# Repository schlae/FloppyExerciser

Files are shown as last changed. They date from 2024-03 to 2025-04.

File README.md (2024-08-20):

# Floppy Exerciser

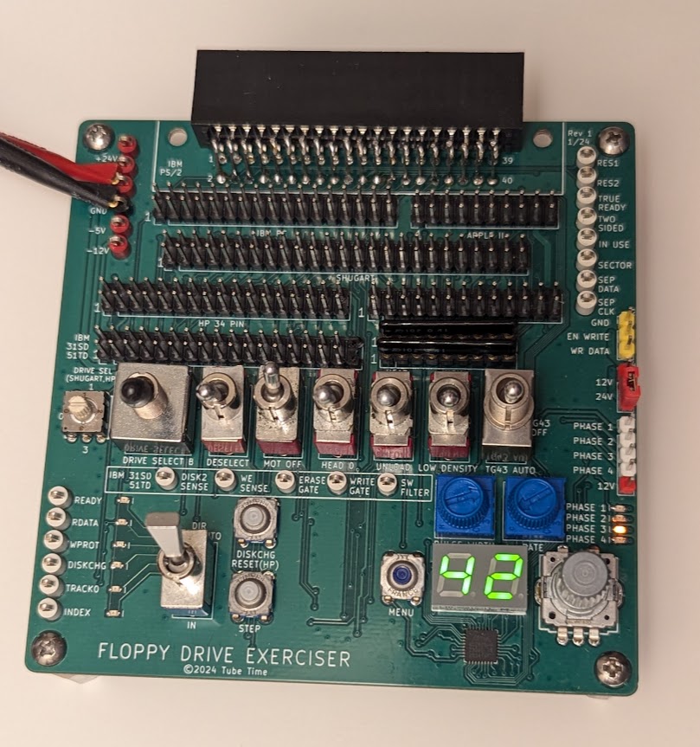
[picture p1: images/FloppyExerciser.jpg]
Floppy exerciser circuit board


This board helps test floppy drives of several different types:

* Standard IBM 34-pin drives (3.5" and 5.25")
* IBM PS/2 40-pin drives with embedded power connections
* Shugart 8" floppy drives
* Apple II (original Disk II)
* HP 34-pin drives (as found in many 9122 enclosures)
* HP 26-pin drives (found in older enclosures and machines)
* IBM 31SD and 51TD floppy drives

The board basically breaks out every signal to a control switch, indicator LED, or test point. It's not designed as a flux imaging tool--it's just a simple way to exercise features of a floppy drive.

There is an optional section of the board that is a step controller for the head stepper motor. This controller has an encoder wheel and a small 7-segment display. It will let you select and automatically step to a particular track.

Features include:

* Two potentiometers control step pulse width and step period (speed)
* Generates TG43 signal (Track greater than 43, for variable write current)
* Alignment mode makes it easy to cycle between track 0, middle, and last track
* Supports half tracking (Apple II) and double tracking modes
* Supports direct stepper motor drive through separate header
* Direct stepper drive supports half track, double track, and 1.5x tracking, useuful for getting 32 tpi from a 48tpi drive
* Auto track 0 seek function will try to locate track 0

The fab files are [here](fab/FloppyExerciserRev2.zip).

The schematic is [here](FloppyExerciser.pdf).

The bill of materials is [here](FloppyExerciser.csv)

## Fabrication notes

The board is 100mm x 100mm, 2 layer, standard 1.6mm thickness.

Use toggle switches, not slide switches, otherwise the silkscreen markings will be reveresed.

Use a 3-position switch for the TG43 switch.

Use SIP sockets for RN1 and RN2 so you can swap in different termination resistor values. I usually use 1K.

Be careful about putting any signals on J2. If EN WRITE gets grounded (the adjacent pin is ground) then it will enable writes on any connected drive, erasing the existing track.

## Connecting Drives

* Apple II: Use connector J12. Apply -12V, +5V, and +12V to the test points on the left side of the board.
* PC: Use connector J6. Apply +5V to the test point on the left side of the board. Connect a Molex connector to the floppy drive for power (+5V and sometimes +12V).
* PS/2: Use connector J11. Apply +5V and +12V to the test points on the left side of the board.
* Shugart: Use connector J9. Apply +5V to the test point on the left side of the board. Connect the drive to power externally (typically +5V, +24V, and 120VAC).
* IBM 31SD/51TD: Use connector J10. The 31SD has fewer pins, line it up with pin 1. Apply +5V, -5V, and +24V to the test points on the left side of the board.
* HP 34-pin: Use connector J7. Apply +5V and +12V to the test points on the left side of the board.
* HP 26-pin: Use connector J8. Apply +5V to the board and external power to the HP drive.

The board can directly drive an external 4-phase stepper motor. Attach the stepper motor to J1 and connect either +12V or +24V power to the test points on the left side, and set jumper J4 to pick the voltage.

## Firmware

### Building the Firmware

The code for the ATMega328PB microcontroller is meant to run without a bootloader and can be built from the command line if you
have installed avr-gcc and avrdude.

```
make
make fuses
make prog
```

Note that the avrdude command lines in the makefile are hard-coded for the usbtiny programmer. You'll want to change that if you have another type of AVR programmer.

The MCU is new enough that your version of avr-gcc and avrdude may not
support it yet, see [here](https://gist.github.com/goncalor/51e1c8038cc058b4379552477255b4e1) for instructions on how to fix that.

The bottom of the board has a standard 6-pin AVR programming header as a surface mount footprint. Since you only need to program it once, you could plug a header into the programmer's cable and physically push it up against the board, or you could temporarily tack-solder it in place. Or just leave it soldered in place and install standoffs in the corners of the board.

### Using the Firmware

On startup, the display will temporarily indicate `HI` and then prompt you for the stepping mode:

* SS - single step
* DS - double step
* HS - half step
* 15 - 1.5x step

Half step mode and 1.5x step are supported on the direct drive stepper motor header and the Apple II header.

Select the mode with the encoder wheel and then push it down to select the option.

The display now indicates the current track. Move the encoder wheel to pick a new track. The display will blink to indicate your desired track. Once you are satisfied with it, push down on the encoder to select that track.

For additional functions, you can push the menu button. Menu options are selected with the encoder wheel:

* HO - Home to track 0. The controller seeks until TRACK0 asserts or it steps by 80 tracks
* A8 - Alignment mode for 80 tracks. In this mode, the encoder switches between track 0, track 39, and track 79
* A7 - Alignment mode for 77 tracks
* A4 - Alignment mode for 40 tracks
* 35 - Alignment mode for 35 tracks

To exit alignment modes, push the menu button.

The board will control the TG43 (track greater than 43) signal used by 8" drives as long as the switch is set to "AUTO".

## Licensing

This work is licensed under a Creative Commons Attribution-ShareAlike 4.0 International License. See [https://creativecommons.org/licenses/by-sa/4.0/](https://creativecommons.org/licenses/by-sa/4.0/).

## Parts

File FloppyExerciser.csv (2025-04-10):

Item | Qty | Reference(s) | Value | Digikey | Mouser
1 | 2 | C1, C2 | 0.1
2 | 1 | D1 | LITEON_LTD-2601G-11 | LTD-2601G-11-ND | 859-LTD-2601G-11
3 | 4 | D2, D4, D6, D8 | LED_ALT | 160-1445-1-ND
4 | 8 | D3, D5, D7, D9, D16, D17, D18, D19 | D_ALT | ES1B-E3/61TGICT-ND
5 | 6 | D10, D11, D12, D13, D14, D15 | LED_Small_Filled | 160-1445-1-ND
6 | 4 | H1, H2, H3, H4 | MH
7 | 1 | J1 | STEPPER
8 | 1 | J2 | WRITE
9 | 1 | J3 | ISP
10 | 1 | J4 | V
11 | 1 | J6 | IBM
12 | 1 | J7 | HP 34-PIN
13 | 1 | J8 | HP 26-PIN
14 | 1 | J9 | SHUGART
15 | 1 | J10 | IBM 31SD
16 | 1 | J11 | PS/2 |  | 587-395-040
17 | 1 | J12 | APPLE II
18 | 8 | Q1, Q2, Q3, Q4, Q5, Q6, Q7, Q8 | ~ |  | 78-SI2318CDS-T1-BE3
19 | 9 | R1, R10, R11, R23, R24, R25, R26, R27, R28 | 10K | RMCF0603JT10K0CT-ND
20 | 8 | R2, R3, R4, R5, R6, R7, R8, R9 | 1K | RMCF0603JT1K0CT-ND
21 | 10 | R12, R13, R14, R15, R16, R17, R18, R19, R20, R21 | 220 | RMCF0603JT220RCT-ND
22 | 1 | R22 | 3.3K | RMCF0603JT3K30CT-ND
23 | 2 | RN1, RN2 | R_Network08 | 4609X-101-102LF
24 | 1 | RV1 | RATE | 3386P-1-202TLF
25 | 1 | RV2 | PW | 3386P-1-202TLF
26 | 1 | SW1 | RotaryEncoder_Switch |  | 667-EVE-YBCAJO16B
27 | 1 | SW2 | STEP | EG1828-ND
28 | 1 | SW3 | DISKCH_RST | EG1828-ND
29 | 1 | SW4 | DSEL | 100DP1T1B1M2QE
30 | 1 | SW5 | DSEL2 | CT3098-ND
31 | 1 | SW6 | DRIVE_SELECT | 100SP1T1B4M2QE
32 | 1 | SW7 | MOTOR_ON | 100SP1T1B4M2QE
33 | 1 | SW8 | HEAD_SEL | 100SP1T1B4M2QE
34 | 1 | SW9 | HEAD_LOAD | 100SP1T1B4M2QE
35 | 1 | SW10 | DIR | 100SP1T1B4M2QE
36 | 1 | SW11 | TG43 MODE | 141-100DP6T3B4M2QE-ND
37 | 1 | SW12 | MENU | EG1828-ND
38 | 1 | SW13 | DENSITY | 100SP1T1B4M2QE
39 | 25 | TP1, TP2, TP3, TP4, TP5, TP6, TP7, TP8, TP9, TP10, TP11, TP12, TP13, TP14, TP15, TP16, TP17, TP18, TP19, TP20, TP21, TP22, TP23, TP24, TP25 | TestPoint | 36-5006-ND
40 | 1 | U1 | ATmega328PB-M | ATMEGA328PB-MU-ND
41 | 1 | U2 | 74LS245 |  | 595-SN74LS245DW
42 | 1 | U3 | 74LS32 |  | 595-SN74LS32DR
43 | 1 | U4 | 74LS04 |  | 595-SN74LS04D

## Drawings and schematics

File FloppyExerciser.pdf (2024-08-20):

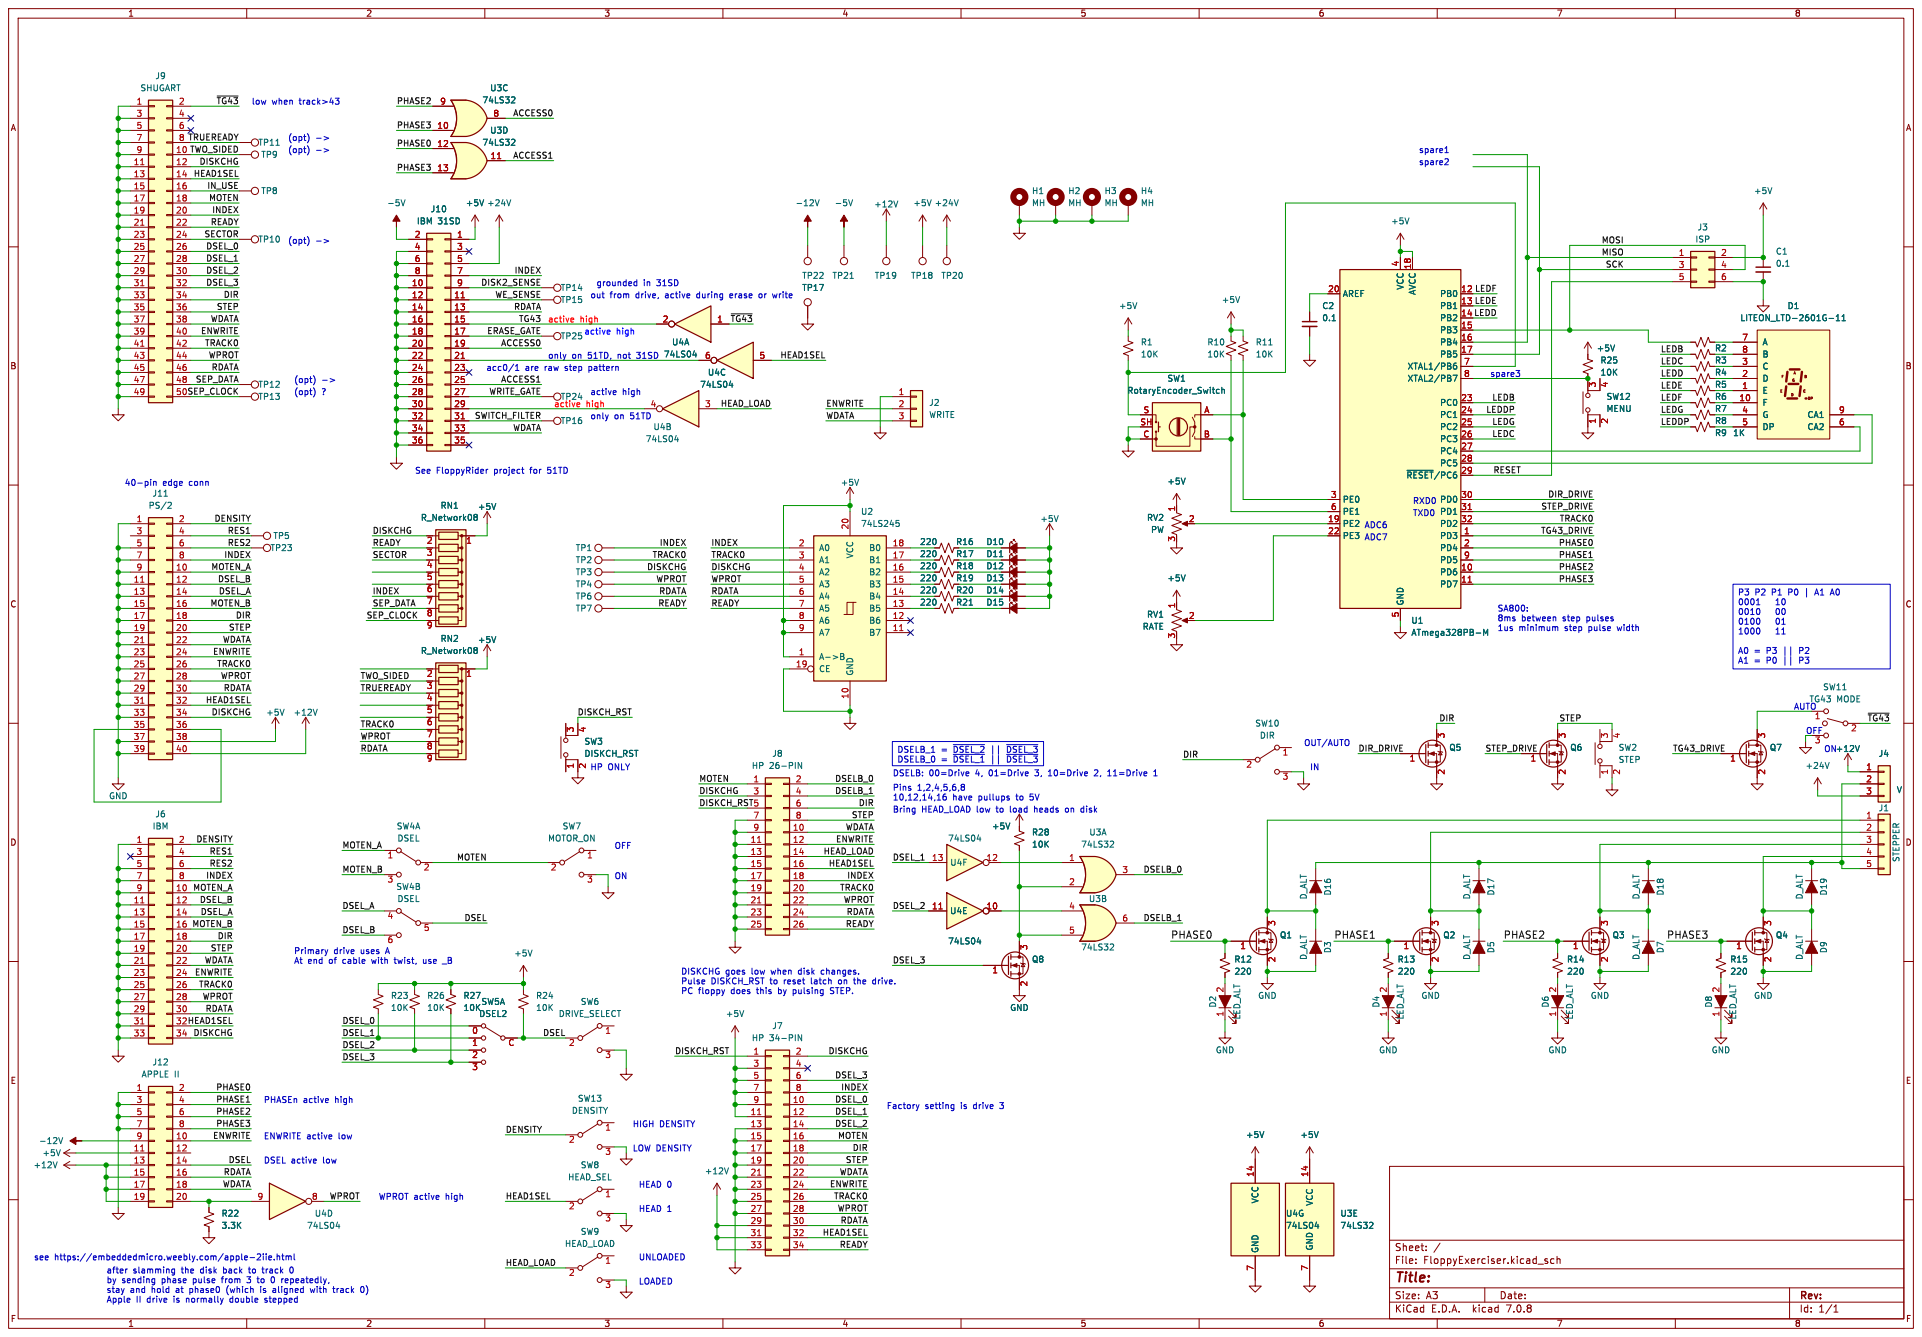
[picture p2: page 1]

At end of cable with twist, use _B

DISKCHG goes low when disk changes. Pulse DISKCH_RST to reset latch on the drive. PC floppy does this by pulsing STEP.

Factory setting is drive 3 HEAD 1
HIGH DENSITY

WPROT active high ENWRITE active low

by sending phase pulse from 3 to 0 repeatedly, stay and hold at phase0 (which is aligned with track 0)

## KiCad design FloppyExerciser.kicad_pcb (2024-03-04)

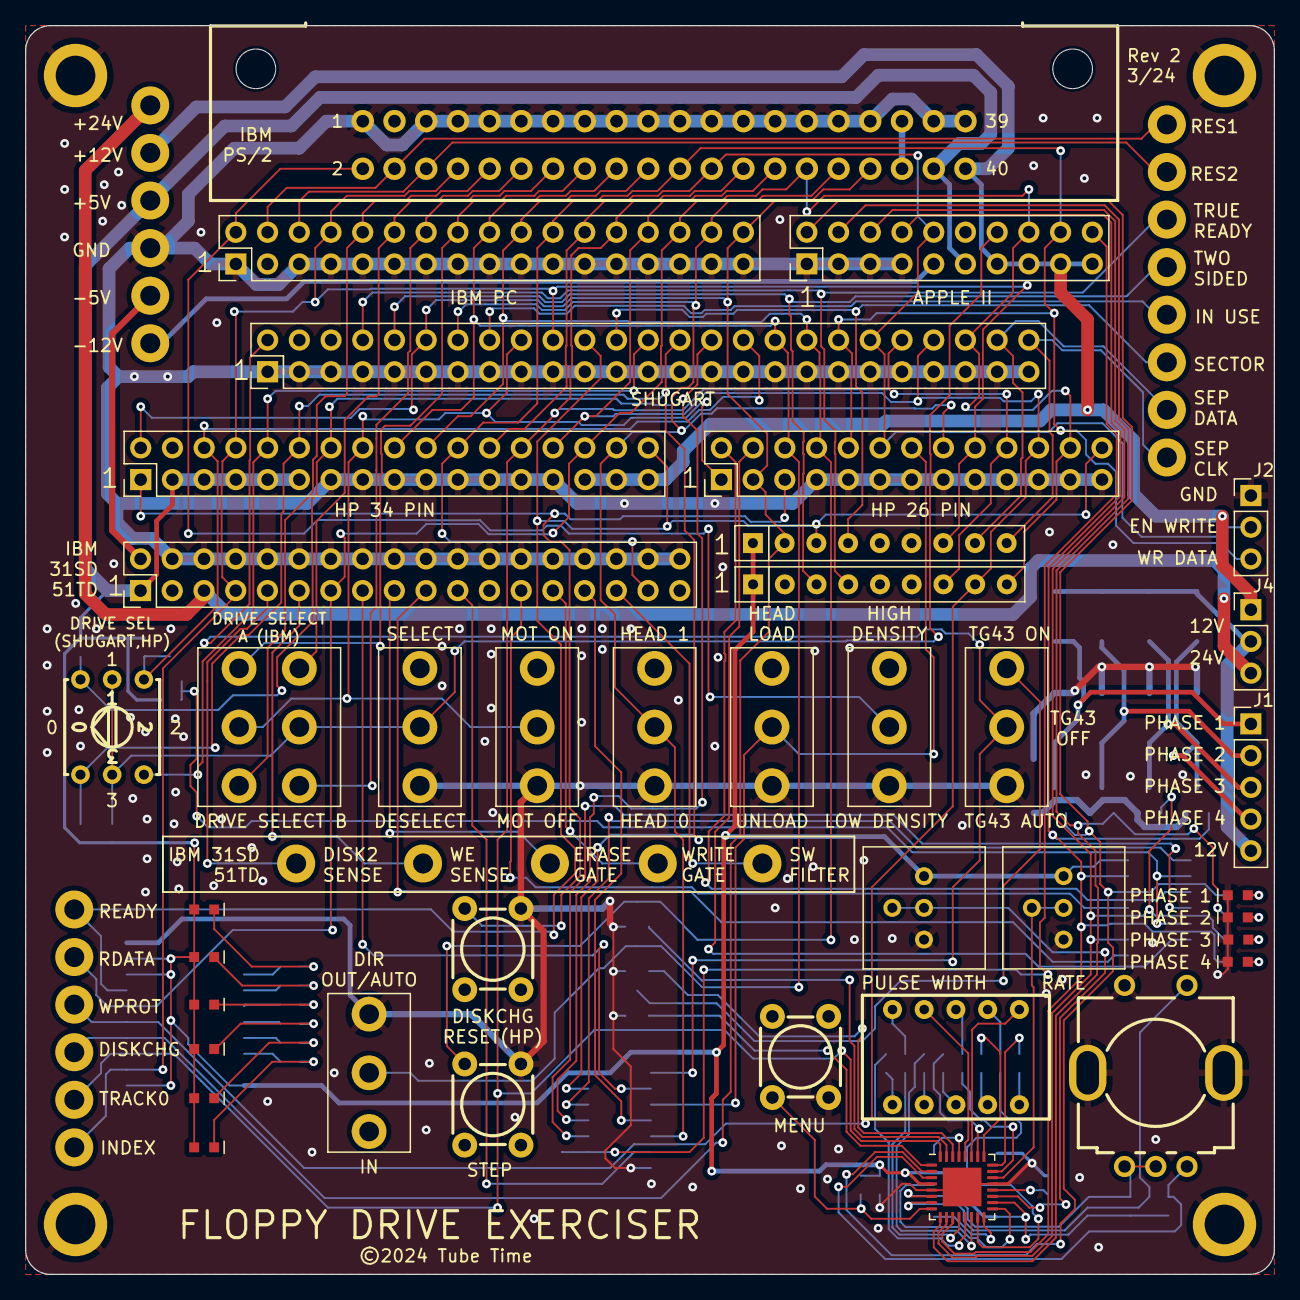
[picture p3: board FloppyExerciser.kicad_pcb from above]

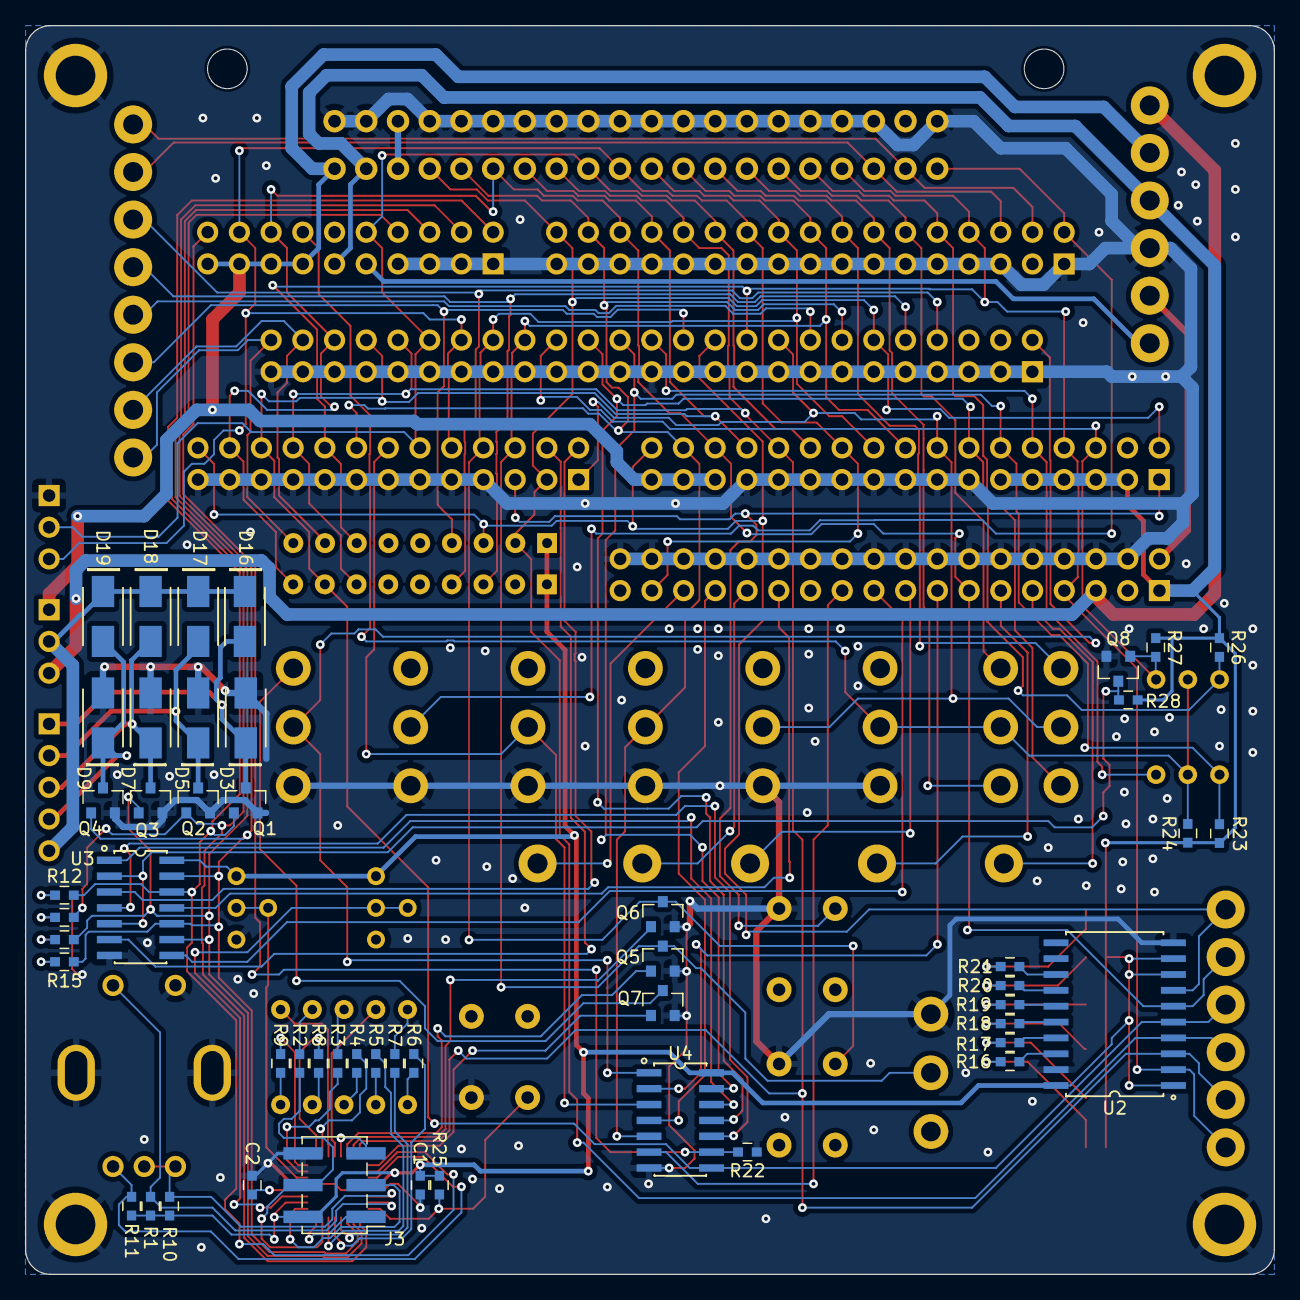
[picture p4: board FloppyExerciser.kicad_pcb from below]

Board: 2 copper layers, 100.0 x 100.0 mm, 118 parts (50 on the bottom side), 113 nets.

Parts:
C1, C2: 0.1; CAPC1608X100
D1: LITEON_LTD-2601G-11; LTD-2601G-11
D2, D4, D6, D8: LED_ALT; LEDM1608X50
D3, D5, D7, D9, D16, D17, D18, D19: D_ALT; DIOM5226X210
D10, D11, D12, D13, D14, D15: LED_Small_Filled; LEDM1608X50
H1, H2, H3, H4: MH; MH_125_200
J1: STEPPER; PinHeader_1x05_P2.54mm_Vertical
J2: WRITE; PinHeader_1x03_P2.54mm_Vertical
J3: ISP; PinHeader_2x03_P2.54mm_Vertical_SMD
J4: V; PinHeader_1x03_P2.54mm_Vertical
J6: IBM; PinHeader_2x17_P2.54mm_Vertical
J7: HP 34-PIN; PinHeader_2x17_P2.54mm_Vertical
J8: HP 26-PIN; PinHeader_2x13_P2.54mm_Vertical
J9: SHUGART; PinHeader_2x25_P2.54mm_Vertical
J10: IBM 31SD; PinHeader_2x18_P2.54mm_Vertical
J11: PS/2; EDAC_395-040-559-212
J12: APPLE II; PinHeader_2x10_P2.54mm_Vertical
Q1, Q2, Q3, Q4, Q5, Q6, Q7, Q8: SOT95P230X117-3
R1, R10, R11, R23, R24, R25, R26, R27, R28: 10K; RESC1608X55
R2, R3, R4, R5, R6, R7, R8, R9: 1K; RESC1608X55
R12, R13, R14, R15, R16, R17, R18, R19, R20, R21: 220; RESC1608X55
R22: 3.3K; RESC1608X55
RN1, RN2: R_Network08; R_Array_SIP9
RV1: RATE; BOURNS_3386_VERT_UNIVERSAL
RV2: PW; BOURNS_3386_VERT_UNIVERSAL
SW1: RotaryEncoder_Switch; PANASONIC_EVEY
SW2: STEP; ESWITCH_TL1105
SW3: DISKCH_RST; ESWITCH_TL1105
SW4: DSEL; SW_DPDT
SW5: DSEL2; CTS_220AD_04
SW6: DRIVE_SELECT; SW_SPDT
SW7: MOTOR_ON; SW_SPDT
SW8: HEAD_SEL; SW_SPDT
SW9: HEAD_LOAD; SW_SPDT
SW10: DIR; SW_SPDT
SW11: TG43 MODE; SW_SPDT
SW12: MENU; ESWITCH_TL1105
SW13: DENSITY; SW_SPDT
TP1, TP2, TP3, TP4, TP5, TP6, TP7, TP8, TP9, TP10, TP11, TP12, TP13, TP14, TP15, TP16, TP17, TP18, TP19, TP20, TP21, TP22, TP23, TP24, TP25: TestPoint; TP_KEYSTONE_5005_9
U1: ATmega328PB-M; QFN-32-1EP_5x5mm_P0.5mm_EP3.1x3.1mm
U2: 74LS245; SOP127P1065X265-20
U3: 74LS32; SOP127P620X175-14
U4: 74LS04; SOP127P620X175-14

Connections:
+5V: C1.1, D10.2 (A), D11.2 (A), D12.2 (A), D13.2 (A), D14.2 (A), D15.2 (A), J3.2, J7.3, J7.5, J7.7, J7.9, J7.11, J10.1, J11.38, J12.11, R1.1, R10.1, R11.1, R23.1, R24.1, R25.1, R26.1, R27.1, R28.1, RN1.1 (common), RN2.1 (common), RV1.1, RV2.1, TP18.1, U1.4 (VCC), U1.18 (AVCC), U2.1 (A->B), U2.8 (A6), U2.9 (A7), U2.20 (VCC), U3.14 (VCC), U4.14 (VCC)
+12V: J4.1, J7.29, J7.31, J7.33, J11.40, J12.13, J12.15, J12.17, J12.19, TP19.1
+24V: J4.3, J10.5, TP20.1
-5V: J10.2, TP21.1
-12V: J12.9, TP22.1
/ACCESS0: J10.19, U3.8
/ACCESS1: J10.25, U3.11
/DENSITY: J6.2, J11.2, SW13.2 (B)
/DIR: J6.18, J7.18, J8.6, J9.34, J11.18, Q5.3 (D), SW10.2 (B)
/DIR_DRIVE: Q5.1 (G), U1.30 (PD0)
/DISK2_SENSE: J10.9, TP14.1
/DISKCHG: J6.34, J7.2, J8.3, J9.12, J11.34, RN1.2 (R1), TP3.1, U2.4 (A2)
/DISKCH_RST: J7.1, J8.5, SW3.4
/DSEL: J12.14, R24.2, SW4.5 (B), SW5.C, SW6.2 (B)
/DSELB_0: J8.2, U3.3
/DSELB_1: J8.4, U3.6
/DSEL_0: J7.10, J9.26, SW5.0
/DSEL_1: J7.12, J9.28, R23.2, SW5.1, U4.13
/DSEL_2: J7.14, J9.30, R26.2, SW5.2, U4.11
/DSEL_3: J7.6, J9.32, Q8.1 (G), R27.2, SW5.3
/DSEL_A: J6.14, J11.14, SW4.4 (A)
/DSEL_B: J6.12, J11.12, SW4.6 (C)
/ENWRITE: J2.2, J6.24, J7.24, J8.12, J9.40, J11.24, J12.10
/ERASE_GATE: J10.17, TP25.1
/HEAD1SEL: J6.32, J7.32, J8.16, J9.14, J11.32, SW8.2 (B), U4.5
/HEAD_LOAD: J8.14, SW9.2 (B), U4.3
/INDEX: J6.8, J7.8, J8.18, J9.20, J10.7, J11.8, RN1.7 (R6), TP1.1, U2.2 (A0)
/IN_USE: J9.16, TP8.1
/LEDB: R3.1, U1.23 (PC0)
/LEDC: R4.1, U1.26 (PC3)
/LEDD: R5.1, U1.14 (PB2)
/LEDDP: R9.1, U1.24 (PC1)
/LEDE: R6.1, U1.13 (PB1)
/LEDF: R7.1, U1.12 (PB0)
/LEDG: R8.1, U1.25 (PC2)
/MISO: J3.1, U1.16 (PB4)
/MOSI: J3.4, R2.1, U1.15 (PB3)
/MOTEN: J7.16, J8.1, J9.18, SW4.2 (B), SW7.2 (B)
/MOTEN_A: J6.10, J11.10, SW4.1 (A)
/MOTEN_B: J6.16, J11.16, SW4.3 (C)
/PHASE0: J12.2, Q1.1 (G), R12.2, U1.2 (PD4), U3.12
/PHASE1: J12.4, Q2.1 (G), R13.2, U1.9 (PD5)
/PHASE2: J12.6, Q3.1 (G), R14.2, U1.10 (PD6), U3.9
/PHASE3: J12.8, Q4.1 (G), R15.2, U1.11 (PD7), U3.10, U3.13
/RDATA: J6.30, J7.30, J8.24, J9.46, J10.13, J11.30, J12.16, RN2.9 (R8), TP6.1, U2.6 (A4)
/READY: J7.34, J8.26, J9.22, RN1.3 (R2), TP7.1, U2.7 (A5)
/RES1: J6.4, J11.4, TP5.1
/RES2: J6.6, J11.6, TP23.1
/RESET: J3.5, U1.29 (~RESET/PC6)
/SCK: J3.3, U1.17 (PB5)
/SECTOR: J9.24, RN1.4 (R3), TP10.1
/SEP_CLOCK: J9.50, RN1.9 (R8), TP13.1
/SEP_DATA: J9.48, RN1.8 (R7), TP12.1
/STEP: J6.20, J7.20, J8.8, J9.36, J11.20, Q6.3 (D), SW2.4
/STEP_DRIVE: Q6.1 (G), U1.31 (PD1)
/SWITCH_FILTER: J10.31, TP16.1
/TG43: J10.15, U4.2
/TG43_DRIVE: Q7.1 (G), U1.1 (PD3)
/TRACK0: J6.26, J7.26, J8.20, J9.42, J11.26, RN2.7 (R6), TP2.1, U1.32 (PD2), U2.3 (A1)
/TRUEREADY: J9.8, RN2.4 (R3), TP11.1
/TWO_SIDED: J9.10, RN2.3 (R2), TP9.1
/WDATA: J2.3, J6.22, J7.22, J8.10, J9.38, J10.33, J11.22, J12.18
/WE_SENSE: J10.11, TP15.1
/WPROT: J6.28, J7.28, J8.22, J9.44, J11.28, RN2.8 (R7), TP4.1, U2.5 (A3), U4.8
/WRITE_GATE: J10.27, TP24.1
/~TG43: J9.2, SW11.2, U4.1
GND: C1.2, C2.2, D2.1 (K), D3.2 (A), D4.1 (K), D5.2 (A), D6.1 (K), D7.2 (A), D8.1 (K), D9.2 (A), H1.1, H2.1, H3.1, H4.1, J2.1, J3.6, J6.1, J6.5, J6.7, J6.9, J6.11, J6.13, J6.15, J6.17, J6.19, J6.21, J6.23, J6.25, J6.27, J6.29, J6.31, J6.33, J7.13, J7.15, J7.17, J7.19, J7.21, J7.23, J7.25, J7.27, J8.7, J8.9, J8.11, J8.13, J8.15, J8.17, J8.19, J8.21, J8.23, J8.25, J9.1, J9.3, J9.5, J9.7, J9.9, J9.11, J9.13, J9.15, J9.17, J9.19, J9.21, J9.23, J9.25, J9.27, J9.29, J9.31, J9.33, J9.35, J9.37, J9.39, J9.41, J9.43, J9.45, J9.47, J9.49, J10.4, J10.6, J10.8, J10.10, J10.12, J10.14, J10.16, J10.18, J10.20, J10.22, J10.24, J10.26, J10.28, J10.30, J10.32, J10.34, J10.36, J11.1, J11.5, J11.7, J11.9, J11.11, J11.13, J11.15, J11.17, J11.19, J11.21, J11.23, J11.25, J11.27, J11.29, J11.31, J11.33, J11.37, J11.39, J12.1, J12.3, J12.5, J12.7, Q1.2 (S), Q2.2 (S), Q3.2 (S), Q4.2 (S), Q5.2 (S), Q6.2 (S), Q7.2 (S), Q8.2 (S), R22.2, RV1.3, RV2.3, SW1.C, SW1.SH, SW2.2, SW3.2, SW6.3 (C), SW7.3 (C), SW8.3 (C), SW9.3 (C), SW10.3 (C), SW11.3, SW12.1, SW13.3 (C), TP17.1, U1.5 (GND), U1.21 (GND), U1.33 (GND), U2.10 (GND), U2.19 (CE), U3.7 (GND), U4.7 (GND)
unnamed: D1.7 (A), R2.2
unnamed: D1.8 (B), R3.2
unnamed: D1.3 (C), R4.2
unnamed: D1.9 (CA1), U1.28 (PC5)
unnamed: D1.6 (CA2), U1.27 (PC4)
unnamed: D1.2 (D), R5.2
unnamed: D1.5 (DP), R9.2
unnamed: D1.1 (E), R6.2
unnamed: D1.10 (F), R7.2
unnamed: D1.4 (G), R8.2
unnamed: D2.2 (A), R12.1
unnamed: D4.2 (A), R13.1
unnamed: D6.2 (A), R14.1
unnamed: D8.2 (A), R15.1
unnamed: D10.1 (K), R16.2
unnamed: D11.1 (K), R17.2
unnamed: D12.1 (K), R18.2
unnamed: D13.1 (K), R19.2
unnamed: D14.1 (K), R20.2
unnamed: D15.1 (K), R21.2
unnamed: D3.1 (K), D16.2 (A), J1.1, Q1.3 (D)
unnamed: D16.1 (K), D17.1 (K), D18.1 (K), D19.1 (K), J1.5, J4.2
unnamed: D5.1 (K), D17.2 (A), J1.2, Q2.3 (D)
unnamed: D7.1 (K), D18.2 (A), J1.3, Q3.3 (D)
unnamed: D9.1 (K), D19.2 (A), J1.4, Q4.3 (D)
unnamed: J10.21, U4.6
unnamed: J10.29, U4.4
unnamed: J11.35, J11.36
unnamed: J12.20, R22.1, U4.9
unnamed: Q7.3 (D), SW11.1
unnamed: Q8.3 (D), R28.2, U3.2, U3.5
unnamed: C2.1, U1.20 (AREF)
unnamed: R11.2, SW1.A, U1.3 (PE0)
unnamed: R10.2, SW1.B, U1.6 (PE1)
unnamed: RV2.2, U1.19 (PE2)
unnamed: RV1.2, U1.22 (PE3)
unnamed: R1.2, SW1.S, U1.7 (XTAL1/PB6)
unnamed: R25.2, SW12.3, U1.8 (XTAL2/PB7)
unnamed: R16.1, U2.18 (B0)
unnamed: R17.1, U2.17 (B1)
unnamed: R18.1, U2.16 (B2)
unnamed: R19.1, U2.15 (B3)
unnamed: R20.1, U2.14 (B4)
unnamed: R21.1, U2.13 (B5)
unnamed: U3.1, U4.12
unnamed: U3.4, U4.10

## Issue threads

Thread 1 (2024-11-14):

Wrong reference for RV1 and RV2 in BOM

laurent-fr, 2024-11-14:
Hi !

In BOM, RV1 and RV2 should be 3386P-1-202TLF instead of 3386F-1-202TLF (wrong footprint - https://www.bourns.com/docs/Product-Datasheets/3386.pdf)

thanks !

schlae, 2024-11-15:
Fixed: https://github.com/schlae/FloppyExerciser/commit/7e459499f52b082e0d4a15c8c32506de48172900

laurent-fr, 2024-11-15:
thx :-)

Closed 2024-11-15.

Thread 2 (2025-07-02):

Add head clean mode

schlae, 2025-07-02:
Select HC from power up menu. It is essentially identical to normal mode but track steps happen instantly, with no need to push the encoder button.

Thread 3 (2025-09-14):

Is the part number correct for sw11 in the bom?

mrthreeplates, 2025-09-14:
141-100DP6T3B4M2QE-ND seems to be a dpdt, should it be 100sp3t1.... instead?

Thanks for for a cool project, can't wait to build it!

BobDarlington, 2025-09-19:
I ordered this part: https://www.digikey.com/en/products/detail/cit-relay-and-switch/ANT13SECQE/12503394 -hopefully I won't be filing pins round.

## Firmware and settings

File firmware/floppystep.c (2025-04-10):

// Fuses E:F7, H:D9, L:E2
#define F_CPU (8000000UL)
#include <avr/io.h>
#include <util/delay.h>
#include <avr/interrupt.h>
#include <inttypes.h>
#include <stdbool.h>
#include <stdlib.h>

#include "segment_font.h"

#define ANODE1 5
#define ANODE2 4
#define C_A 3 // PB
#define C_D 2 // PB
#define C_E 1 // PB
#define C_F 0 // PB

#define PIN_MENU_BUTTON 7 // PB
#define PIN_ENC_BUTTON 6 // PB

#define C_C 3 // PC
#define C_G 2 // PC
#define C_DP 1 // PC
#define C_B 0 // PC

#define PIN_DIR 0 // PD
#define PIN_STEP 1 // PD
#define PIN_TRACK0 2 // PD
#define PIN_TG43 3 // PD

// Averaging filter for removing ADC noise
#define FILT_BITS (5)    // Number of fixed point fractional bits
#define AVG_FILT(input, output)  output = (output - (output >> FILT_BITS) + (input))
#define GET_AVG(v) ((v + _BV(FILT_BITS) / 2) >> FILT_BITS) // Rounds up

#define STEP_MODE_WHOLE 0
#define STEP_MODE_DOUBLE 1
#define STEP_MODE_HALF 2
#define STEP_MODE_15 3 // Step-and-a half mode

uint8_t step_mode = 0;

volatile uint8_t dpoints = 0;
volatile char displaychars[2];
volatile bool blink = false;

uint8_t adc_chan = 0;

uint16_t val_pw = 0;
uint16_t val_rate = 0;
volatile uint16_t val_vref = 0;
uint8_t val_range = 0;

volatile uint16_t val_actual_rate = 0;
volatile uint16_t val_actual_pw = 0;
volatile uint16_t val_actual_pw_old = 0;
uint8_t disp_freq = 0;
uint8_t disp_duty = 0;

// Wheel tracking state
volatile int16_t wheel_val;
uint8_t wheel_state_old = 0;
volatile uint16_t blink_counter = 0;

volatile int16_t sel_track = 0;
volatile int16_t cur_track = 0;

// Puts a digit on the 7-segment display
void load_digit(uint8_t val, uint8_t anode)
{
//   AAA       DDD
//  F   B     C   E
//   GGG       GGG
//  E   C     B   F
//   DDD       AAA
//              26x1 0345
// 0000 0000 -> CG.B ADEF

    uint8_t d2 = ~segment_font_table[val]; // Invert bits since LED on when 0
    uint8_t d;
    uint8_t dpoint;

    // Remap segment font to our GPIO mapping
    d = (d2 & 0x3) << 3; // Bits 0 and 1
    d |= (d2 & _BV(2)) << 5; // Bit 2
    d |= (d2 & _BV(3)) >> 1; // Bit 3
    d |= (d2 & _BV(4)) >> 3; // Bit 4
    d |= (d2 & _BV(5)) >> 5; // Bit 5
    d |= (d2 & _BV(6)); // Bit 6
    d |= _BV(5); // DP off by default

    dpoint = (dpoints >> (anode - 1)) & 1;

    PORTB = d & 0x0F;
    PORTC = ((anode << 4) | (d >> 4)) & ~(dpoint << 1);
}

// Timer interrupt for display
ISR(TIMER0_COMPA_vect)
{

    static uint8_t counter = 0;

    counter++;

    // Should display be blank?
    if (!blink || (counter & 0x80)) {
        // Alternate between digits
        if (PORTC & _BV(5)) {
            load_digit(displaychars[1], 1);
        } else {
            load_digit(displaychars[0], 2);
        }
    } else {
        load_digit(0, 0);
    }

}

// Display binary value
void disp_bin(int16_t val)
{
    char c[10];
    if (val > 199) val = 199;
    if (val < -9) val = -9;
    itoa(val, c, 10);
    // Right justify result
    if ((val < 10) && (val > -1)) {
        displaychars[0] = ' ';
        displaychars[1] = c[0];
        dpoints &= ~_BV(1);
    } else if (val >= 100) {
        displaychars[0] = c[1];
        displaychars[1] = c[2];
        dpoints |= _BV(1); // This is our hundreds digit
    } else {
        displaychars[0] = c[0];
        displaychars[1] = c[1];
        dpoints &= ~_BV(1);
    }
}

// Set the ADC channel mux
void adc_set_chan(uint8_t chan)
{
    ADMUX = (ADMUX & 0xF0) | (chan & 0xf);
    adc_chan = chan;
}

// Convert all ADC channels and filter results
ISR(ADC_vect)
{
    switch (adc_chan) {
        case 0x6: // Pulse width
            AVG_FILT(255 - ADCH, val_pw);
            adc_set_chan(0x7);
            val_actual_pw = (GET_AVG(val_pw));
            if (val_actual_pw != val_actual_pw_old) {
                val_actual_pw_old = val_actual_pw;
            }
            break;
        case 0x7: // Pulse rate
            AVG_FILT(255 - ADCH, val_rate);
            adc_set_chan(0xe);
            val_actual_rate = (GET_AVG(val_rate));
            break;
        default:
        case 0xe: // Internal bandgap reference voltage
            AVG_FILT(ADCH, val_vref);
            adc_set_chan(0x6);
            break;
    }
    _delay_us(100);
    ADCSRA |= _BV(ADSC);
}

void wheel_increment()
{
    blink_counter = 0;
    wheel_val++;
    if (wheel_val > 199) wheel_val = 199;
}

void wheel_decrement()
{
    blink_counter = 0;
    wheel_val--;
    if (wheel_val < -9) wheel_val = -9;
}

// Interrupt on change for encoder
ISR(PCINT3_vect)
{
    uint8_t wheel_state = PINE & 0x3;
    uint8_t st = wheel_state | (wheel_state_old << 4);
    // Compare to wheel_state_old, ignore B input due to detent.
    if (wheel_state != wheel_state_old) {
        // Present state, next state
        // 00 -> 01 clockwise
        // 10 -> 11 counterclockwise
        // 11 -> 10 clockwise
        // 01 -> 00 counterclockwise
        if ((st == 0x01) || (st == 0x32)) {
            wheel_increment();
        }
        if ((st == 0x23) || (st == 0x10)) {
            wheel_decrement();
        }
        wheel_state_old = wheel_state;
    }
}

// Time that step pulse is active
void pulse_delay()
{
    int count;
    for (count = 0; count < val_actual_pw; count++) {
        _delay_us(1);
    }
}

uint8_t a2_step_table_single[] = {1, 2, 4, 8, 1, 2, 4, 8};
uint8_t a2_step_table_half[] = {1, 3, 2, 6, 4, 12, 8, 9};

// Sets manual stepper pins to specified position
void set_step(uint8_t pos)
{
    PORTD &= 0x0F; // MS nybble is our stepper drive
    if ((step_mode == STEP_MODE_HALF) || (step_mode == STEP_MODE_15)) {
        PORTD |= (a2_step_table_half[pos & 0x7]) << 4;
    } else {
        PORTD |= (a2_step_table_single[pos & 0x7]) << 4;
    }
}

// Timer interrupt for pulsing stepper
ISR(TIMER3_COMPA_vect)
{
    int16_t sel_track_phy;
    int16_t track43 = 43;

    if (step_mode == STEP_MODE_DOUBLE) {
        sel_track_phy = sel_track * 2;
        track43 = 43 * 2;
    } else if (step_mode == STEP_MODE_15) {
        sel_track_phy = sel_track * 3; // Three half-steps
        track43 = 43 * 3 / 2;
    } else {
        sel_track_phy = sel_track;
    }

    if (sel_track_phy > cur_track) {
        // Pulse increment, step in
        cur_track++;
        PORTD |= _BV(PIN_DIR);
        _delay_us(10);
        PORTD |= _BV(PIN_STEP);
        set_step(cur_track);
        pulse_delay();
        PORTD &= ~_BV(PIN_STEP);
        _delay_us(10);
        PORTD &= ~_BV(PIN_DIR);
    }

    if (sel_track_phy < cur_track) {
        // Pulse decrement, step out
        cur_track--;
        PORTD &= ~_BV(PIN_DIR);
        _delay_us(10);
        PORTD |= _BV(PIN_STEP);
        set_step(cur_track);
        pulse_delay();
        PORTD &= ~_BV(PIN_STEP);
    }

    // Update step timer from ADC

    // Nominal value of 128 = 16ms, which is a good typical step time
    // (if a bit slow).
    // Min is 0 >> 1 + 1 = 1 (0.1ms)
    // Max is 255 >> 1 + 1 = 128 (16ms)
    // Middle scale is 127 >> 1 + 1 = 64 (8ms)

    // Timer is 0.128ms per bit
    OCR3A = (val_actual_rate >> 1) + 1;

    // Update TG43 signal
    if (cur_track >= track43) {
        PORTD |= _BV(PIN_TG43);
    } else {
        PORTD &= ~_BV(PIN_TG43);
    }
}

// Check debounced state of menu button
bool menu_button_check()
{
    static uint8_t debounce = 0;
    if (!(PINB & _BV(PIN_MENU_BUTTON))) {
        if (debounce < 10) {
            debounce++;
            if (debounce == 10) {
                return true;
            }
        }
    } else {
        debounce = 0;
    }
    return false;
}

// Single step, double step, half step, 1.5x step
char step_menu_table[][2] = {"SS", "DS", "HS", "15"};

// Menu picker UI
int8_t select_menu(char menu_array[][2], uint8_t max_items)
{
    int16_t old_wheel = wheel_val;
    int8_t menu_selection = 0;
    int8_t picked;
    while (1) {
        menu_selection = wheel_val;
        if (menu_selection >= max_items) {
            menu_selection = max_items - 1;
            wheel_val = max_items - 1;
        }

        if (menu_selection < 0) {
            menu_selection = 0;
            wheel_val = 0;
        }

        // Hitting menu button again exits the menu
        if (menu_button_check()) {
            picked = -1;
            break;
        }

        // Show the menu option
        displaychars[0] = menu_array[menu_selection][0];
        displaychars[1] = menu_array[menu_selection][1];

        // When encoder button is pushed, select the item
        if (!(PINB & _BV(PIN_ENC_BUTTON))) {
            picked = menu_selection;
            break;
        }
        _delay_ms(1);
    }
    wheel_val = old_wheel;
    return picked;
}

// Menu on powerup selects type of step
void step_select_menu()
{
    int8_t val = select_menu(step_menu_table, 4);
    if (val != -1) step_mode = val;
}

// Alignment mode
void align_mode(uint8_t max_track)
{
    int16_t old_wheel = wheel_val;
    int16_t prev_wheel = wheel_val;
    wheel_val = 0;
    sel_track = 0; // Go to track 0

    while (1)
    {
        // Check for exit
        if (menu_button_check()) {
            wheel_val = old_wheel;
            return;
        }

        // Limit wheel position
        if (wheel_val > 2) {
            wheel_val = 2;
        }
        if (wheel_val < 0) {
            wheel_val = 0;
        }

        // Check for change
        if (wheel_val != prev_wheel) {
            prev_wheel = wheel_val;

            switch (wheel_val) {
                case 0:
                default:
                    sel_track = 0;
                    break;
                case 1:
                    sel_track = max_track >> 1;
                    break;
                case 2:
                    sel_track = max_track;
                    break;
            }
        }

        disp_bin(cur_track);
        _delay_ms(1);
    }
}

// Go find track 0
void homing_mode()
{
    sel_track = -80;
    _delay_ms(10);
    while (1) {
        if (cur_track == sel_track) {
            // Bumped against hard stop? Regardless, we're done.
            cur_track = 0;
            sel_track = 0;
            wheel_val = 0;
            return;
        }

        // Stop early if we hit track0 signal
        if (!(PIND & _BV(PIN_TRACK0))) {
            // Track0 pin has asserted
            cli();
            sel_track = 0;
            cur_track = 0;
            wheel_val = 0;
            sei();
            return;
        }
    }
}


// Options are Home, Align 80 track, Align 40 track, Align 35 track
char main_menu_table [][2] = {"HO", "A8", "A7", "A4", "35"};

// Main menu
void main_menu()
{
    int8_t val;
    val = select_menu(main_menu_table, 5);

    switch(val) {
        default:
        case -1:
            break;
        case 0:
            homing_mode();
            break;
        case 1:
            align_mode(79);
            break;
        case 2:
            align_mode(76);
            break;
        case 3:
            align_mode(39);
            break;
        case 4:
            align_mode(34);
            break;
    }
}

int main (void)
{

    // Set up IO ports
    DDRD = 0xFB; // Track0 sensor input, all others are outputs
    PORTD = 0x04; // Pullup on Track0 input
    DDRB = 0x0F; // Output for LED cathode drivers
    DDRC = 0x3F; // Output for LED cathode and anode drivers
    DDRE = 0x00; // Wheel inputs, ADC inputs

    // Setup interrupt on change
    PCMSK3 = _BV(PCINT25) | _BV(PCINT24); // For encoder
    PCICR = _BV(PCIE3);

    // Setup display timer
    TCCR0A = _BV(WGM01); // CTC mode
    TCCR0B = 4; // Divide by 256
    OCR0A = 32; // 1ms timer
    TIMSK0 = _BV(OCIE0A); // Interrupt on match

    // Setup step timer
    TCCR3A = 0;
    TCCR3B = _BV(WGM32) | 5; // Divide by 1024.
    OCR3A = 63;
    TIMSK3 = _BV(OCIE3A); // Interrupt on compare match

    // Setup ADC
    ADMUX = _BV(REFS0) | _BV(ADLAR); // Left adjust results, Vref=VCC.
    ADCSRA = _BV(ADEN) | _BV(ADIE) | 7; // Division factor of 128
    adc_set_chan(6);
    sei();
    ADCSRA |= _BV(ADSC);

    // Greet string
    dpoints = 0;
    displaychars[0] = 'H';
    displaychars[1] = 'I';

    _delay_ms(700);

    step_select_menu();

    set_step(0); // Set manual stepper control to phase 0

    while (1) {

        // Selecting a new track
        if (wheel_val != sel_track) {
            if (!blink) {
                blink = true;
                blink_counter = 0;
            }
            disp_bin(wheel_val);
        } else {
            blink = false;
            disp_bin(sel_track);
        }

        // Check for selection timeout
        if (blink) {
            blink_counter++;
            if (blink_counter > 2000) {
                blink = false;
                wheel_val = sel_track;
            }
        }

        // Check for wheel button
        if (!(PINB & _BV(PIN_ENC_BUTTON)) & blink) {
            blink = false;
            sel_track = wheel_val;
        }

        // Check for menu button
        if (menu_button_check()) {
            main_menu();
        }

        _delay_ms(1);

    }
    return 0;
}

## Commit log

2024-03-02 Improve LED routine. Add initial step menu.
2024-03-02 Add menu button and homing mode
2024-03-02 Add 77 track support to align mode
2024-03-04 Rev2 fab with minor fixes for HP 26 pin
    [FloppyExerciser.kicad_pcb, FloppyExerciser.kicad_sch]
2024-08-20 Update readme, add fab and bom
    [FloppyExerciser.csv, FloppyExerciser.kicad_sch]
2024-11-15 Fix potentiometer part number
    [FloppyExerciser.csv, FloppyExerciser.kicad_sch]

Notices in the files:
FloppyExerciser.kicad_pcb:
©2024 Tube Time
